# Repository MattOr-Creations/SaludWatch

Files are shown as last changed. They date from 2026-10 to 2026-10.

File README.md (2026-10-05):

# SaludWatch
The SaludWatch is a monitoring aid device to help track temperature, blood oxy and heart rate while also showing you the time. 
These functions help elderly people track their vitals and know when to take medicine without having to walk to get a device, its simple design makes it easy to understand.

I came up with the idea thanks to my grandma(As weird as it may sound). It all started with my grandma having to climb the stairs to the third floor of my three-story house because she felt dizzy, it was too much! Plus it was dangerous,
one might say "But can't you just move the monitoring aid to the first floor so she doesn't have to go all the way up?" That's an option, yes, however, my grandma likes having her items organized, moving it to the first floor would just make her forget it's there in the first place.
That's when I thought of a great invention, what if the monitoring aid was ON her at ALL times? It would probably look ugly, however if I disguise it as another device which is on you MOST of the time, like a watch, then it would be better!
And that's how SaludWatch was born, the Wi-Fi, LED and buzzer functions were added later after discovering what the ESP32-WROOM-32 has(And can do).



(Schematic of the SaludWatch)

## Now, let's get technical, how does it really work?

+ The sensors, display, buzzer, and buttons connect to an ESP32-WROOM-32 development board.
+ The board reads the sensors, draws everything on a small OLED display, and uses its built-in Wi-Fi to sync the time and send alerts.
+ A LiPo battery powers it through a TP4056 charging module with battery protection (Using the USB charger).
+ And a MT3608 step-up converter raises the battery voltage to the 5V the board needs.

```mermaid
graph TD;
    USBCharger-->TP4056;
    TP4056-->SlideSwitch;
    TP4056-->3.7VLiPobattery
    SlideSwitch-->MT3608;
    MT3608-->ESP32-WROOM-32;
    MAX30102-->|I2C|ESP32-WROOM-32;
    DS18B20-->|1-Wire|ESP32-WROOM-32;
    Buttons-->ESP32-WROOM-32;
    ESP32-WROOM-32-->|I2C|1.3inOLEDdisplay;
    ESP32-WROOM-32-->Buzzer+LED;
    ESP32-WROOM-32-->|Wi-Fi|AlertToFamily;
```

### Expected program flow
1. Boot, connect to Wi-Fi and sync to the local time zone then disconnect(Other modules are still active)
2. Time will show, the screen wakes up if any button is pressed.
3. Press the forward button to send a measurement request, wait 15-30 seconds after a "Keep still" notice, then show results on the OLED.
4. If the old person needs to take medicine soon or something is off, the buzzer will sound and the LED flash, an alert will ONLY be sent If something is off.
5. Otherwise the old person can check their vitals and then the device goes into energy-saving mode, wakes up on a button press.

## ESSENTIAL file locations

- `Hardware/` — 3D Case design and Schematic with wiring using labels
- `Hardware/Case/3DCase.f3d` — 3D Case design
- `Hardware/kicad/SaludWatch.kicad_pro` — Kicad Schematic + Wiring
- `Hardware/kicad/SaludWatch.kicad_sch` — Kicad Schematic + Wiring
- `Firmware/` — Code? Not yet, planned for the future functional prototype
- `Docs/` — Misc, non-editable files, diagrams and layout

## Layout + 3D design
The final third design of all my drawn designs, had to do a box because 3D modelling is hard ;(. (Especially considering I have never done it, I was happy once I found out I could make any weird shaped figure with the line and extrude tool!)


Board layout which I used to make the 3D Case model


Exterior view, here we can see the lid, walls and strap lugs. The lid has one hole for the OLED display and two square sized ones for the two buttons. At the strap lugs' side we can also see the slideSwitch hole and to the side another one for the DS18B20


(Only-Base view, see that hole in the distance? That's for the ESP32-WROOM32, and also opposite hole to the DS18B20 hole is for the micro-usb charger for the TP4056)


Lid+2layer view. Here we can appreciate the beautifully modelled lid, I even made a fit-able lid using the join operation with the extrude tool! And about the two layers, that coin sized hole is for the connections between all the modules. The layers aren't really attached at all, there's an space of 0.3mm from all sides with the two shelves I made[You can see them in the second pic]

## Materials list
Prices were in Peruvian soles(Since I live in Peru) so I calculated the prices using the exchange rate of Sol -> USD:
| # | Part | Qty | Unit price ($) | Total ($) | Where to buy |
|---|---|---|---|---|---|
| 1 | ESP32-WROOM-32 38-pin dev board | 1 | $11.60 | $11.60 | [Nanoparuro](https://nanoparuro.com/shop/esp32-wroom-32-c-esp-32-placa-de-desarrollo-entrada-c-38-pines-wifi-bt-1604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) |
| 2 | USB-TC 1 meter | 1 | 2.90 | 2.90 | [Nanoparuro](https://nanoparuro.com/shop/usb-tc-cable-usb-a-tipo-c-para-transferir-datos-de-1-metro-usb-tc-1610#attr=) |
| 3 | MAX30102 pulse oximeter module | 1 | 2.90 | 2.90 | [Nanoparuro](https://nanoparuro.com/shop/max30102-modulo-sensor-de-pulso-de-ritmo-cardiaco-pulsioximetro-pulsimetro-oximetro-max30102-1672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) |
| 4 | OLED 0.96in I2C display | 1 | 5.80 | 5.80 | [Nanoparuro](https://nanoparuro.com/shop/oled096-i2c-display-oled-0-96-pulgadas-i2c-oled096-i2c-1111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) |
| 5 | DS18B20 waterproof temperature probe | 1 | 2.90 | 2.90 | [Nanoparuro](https://nanoparuro.com/shop/ds18b20-cable-sensor-de-temperatura-digital-ds18b20-a-prueba-de-agua-55degc-a-125degc-304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) |
| 6 | TP4056 charger with protection | 1 | 1.42 | 1.42 | [Nanoparuro](https://nanoparuro.com/shop/tp4056-prot-tp4056-prot-cargador-con-proteccion-para-baterias-de-litio-3-7v-con-entrada-micro-usb-233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) |
| 7 | MT3608 step-up converter | 1 | 1.60 | 1.60 | [Nanoparuro](https://nanoparuro.com/shop/mt3608-mt3608-conversor-dc-dc-step-up-ajustable-2-a-24-vsal-28v-242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) |
| 8 | Slide switch KBB-20 | 1 | 0.35 | 0.35 | [Nanoparuro](https://nanoparuro.com/shop/kbb-20-switch-deslizable-2-posiciones-kbb-20-132?search=KBB-2&order=name+asc#attr=) |
| 9 | 3.7V 1000 mAh LiPo battery | 1 | 4.35 | 4.35 | [Nanoparuro](https://nanoparuro.com/shop/bateria-de-3-7v-litio-366?search=Bateria&order=name+asc#attr=550) |
| 10 | D830B Multimeter | 1 | 5.79 | 5.79 | [Nanoparuro](https://nanoparuro.com/shop/dt-830d-multimetro-digital-con-puntas-de-prueba-d830b-203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) |
| | **Total** | | | **$39.61** | **about $39.61** |

## Limitations
Some parts such as the ESP32 board, the battery, the step up, and DS18B20 are very large and are only meant to prove the functionality of the prototype, they will change in a later version(They are also the only ones I found available near my hometown). I might also have mentioned that a blood pressure module would be added, but since they are VERY expensive(40$) and exceed the budget, those will be totally optional.

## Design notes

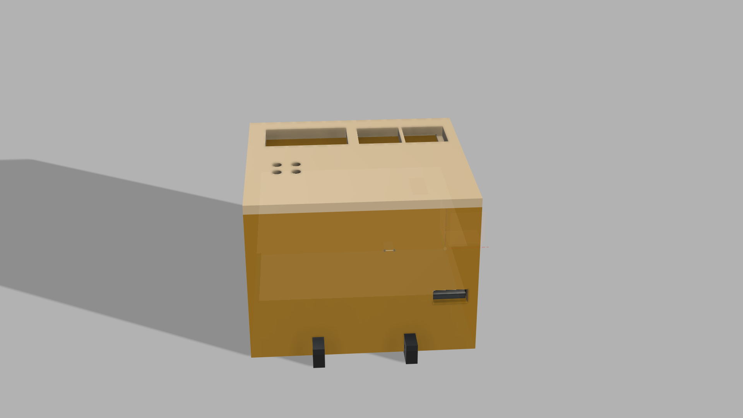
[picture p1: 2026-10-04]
Docs/SaludWatch3D.png

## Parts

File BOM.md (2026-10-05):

# SaludWatch — bill of materials

<!-- Generated by Half Life from project cmuovdwnd01sl01s1f6d9b2td. Edits here are overwritten on the next sync. -->
<!-- Generated: 2026-10-05T01:47:07.764Z -->

> [!NOTE]
> This parts list is mirrored from [Half Life](https://halflife.hackclub.com). Editing it here will not change the platform's copy, and the next sync overwrites this file.

| Week | Tier | Parts funding |
| --- | --- | --- |
| Warm-up | Tier 2 | $65.00 |

| Part | What it's for | Qty | Unit | Total | Vendor |
| --- | --- | --- | --- | --- | --- |
| [OLED 0.96inch 12c display](https://nanoparuro.com/shop/oled096-i2c-display-oled-0-96-pulgadas-i2c-oled096-i2c-1111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) | Display | 1 | $5.80 | $5.80 | [Nanoparuro](https://nanoparuro.com/shop/oled096-i2c-display-oled-0-96-pulgadas-i2c-oled096-i2c-1111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) |
| [TP4056 charger with protection](https://nanoparuro.com/shop/tp4056-prot-tp4056-prot-cargador-con-proteccion-para-baterias-de-litio-3-7v-con-entrada-micro-usb-233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) | Charging the battery | 1 | $1.42 | $1.42 | [Nanoparuro](https://nanoparuro.com/shop/tp4056-prot-tp4056-prot-cargador-con-proteccion-para-baterias-de-litio-3-7v-con-entrada-micro-usb-233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) |
| [3.7V 1000 mAh LiPo battery](https://nanoparuro.com/shop/bateria-de-3-7v-litio-366?search=Bateria&order=name+asc#attr=550) | Power | 1 | $4.35 | $4.35 | [Nanoparuro](https://nanoparuro.com/shop/bateria-de-3-7v-litio-366?search=Bateria&order=name+asc#attr=550) |
| [MAX30102  pulse oximeter module](https://nanoparuro.com/shop/max30102-modulo-sensor-de-pulso-de-ritmo-cardiaco-pulsioximetro-pulsimetro-oximetro-max30102-1672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) | Heart rate sensor | 1 | $2.90 | $2.90 | [Nanoparuro](https://nanoparuro.com/shop/max30102-modulo-sensor-de-pulso-de-ritmo-cardiaco-pulsioximetro-pulsimetro-oximetro-max30102-1672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) |
| [DS18B20 waterproof probe](https://nanoparuro.com/shop/ds18b20-cable-sensor-de-temperatura-digital-ds18b20-a-prueba-de-agua-55degc-a-125degc-304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) | Temperature sensor | 1 | $2.90 | $2.90 | [Nanoparuro](https://nanoparuro.com/shop/ds18b20-cable-sensor-de-temperatura-digital-ds18b20-a-prueba-de-agua-55degc-a-125degc-304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) |
| [KBB-20](https://nanoparuro.com/shop/kbb-20-switch-deslizable-2-posiciones-kbb-20-132?search=KBB-2&order=name+asc#attr=) | Power Switch | 1 | $0.35 | $0.35 | [Nanoparuro](https://nanoparuro.com/shop/kbb-20-switch-deslizable-2-posiciones-kbb-20-132?search=KBB-2&order=name+asc#attr=) |
| [ESP32-WROOM-32](https://nanoparuro.com/shop/esp32-wroom-32-c-esp-32-placa-de-desarrollo-entrada-c-38-pines-wifi-bt-1604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) | Wi-Fi and the main loop | 1 | $11.60 | $11.60 | [Nanoparuro](https://nanoparuro.com/shop/esp32-wroom-32-c-esp-32-placa-de-desarrollo-entrada-c-38-pines-wifi-bt-1604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) |
| [D830B Multimeter](https://nanoparuro.com/shop/dt-830d-multimetro-digital-con-puntas-de-prueba-d830b-203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) | To calibrate MT3608 | 1 | $5.79 | $5.79 | [Nanoparuro](https://nanoparuro.com/shop/dt-830d-multimetro-digital-con-puntas-de-prueba-d830b-203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) |
| [MT3608 step up](https://nanoparuro.com/shop/mt3608-mt3608-conversor-dc-dc-step-up-ajustable-2-a-24-vsal-28v-242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) | Power adapter | 1 | $1.60 | $1.60 | [Nanoparuro](https://nanoparuro.com/shop/mt3608-mt3608-conversor-dc-dc-step-up-ajustable-2-a-24-vsal-28v-242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) |
| [USB-TC 1 meter](https://nanoparuro.com/shop/usb-tc-cable-usb-a-tipo-c-para-transferir-datos-de-1-metro-usb-tc-1610#attr=) | Charging purposes | 1 | $2.90 | $2.90 | [Nanoparuro](https://nanoparuro.com/shop/usb-tc-cable-usb-a-tipo-c-para-transferir-datos-de-1-metro-usb-tc-1610#attr=) |
| **Parts subtotal** | — | — | — | **$39.61** | — |
| **Tax & shipping** | — | — | — | **$0.00** | — |
| **Total** | — | — | — | **$39.61** | — |

$25.39 left of the tier's funding.

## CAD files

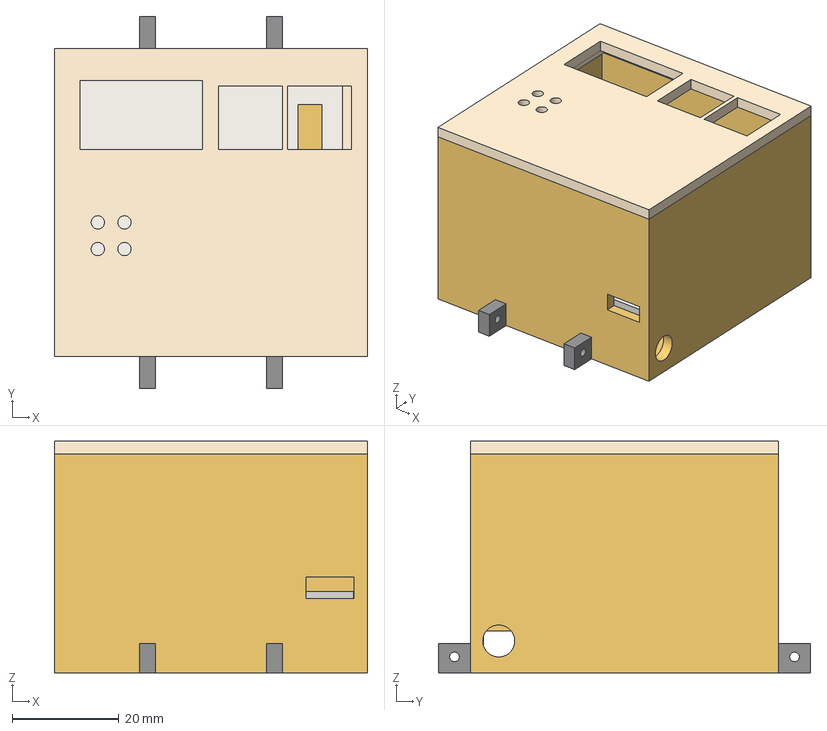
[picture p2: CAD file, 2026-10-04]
Hardware/Case/3DCase.step
58.8 x 69.8 x 43.5 mm

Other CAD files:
Hardware/Case/3DCase.f3d
Hardware/Case/3DCase.stl

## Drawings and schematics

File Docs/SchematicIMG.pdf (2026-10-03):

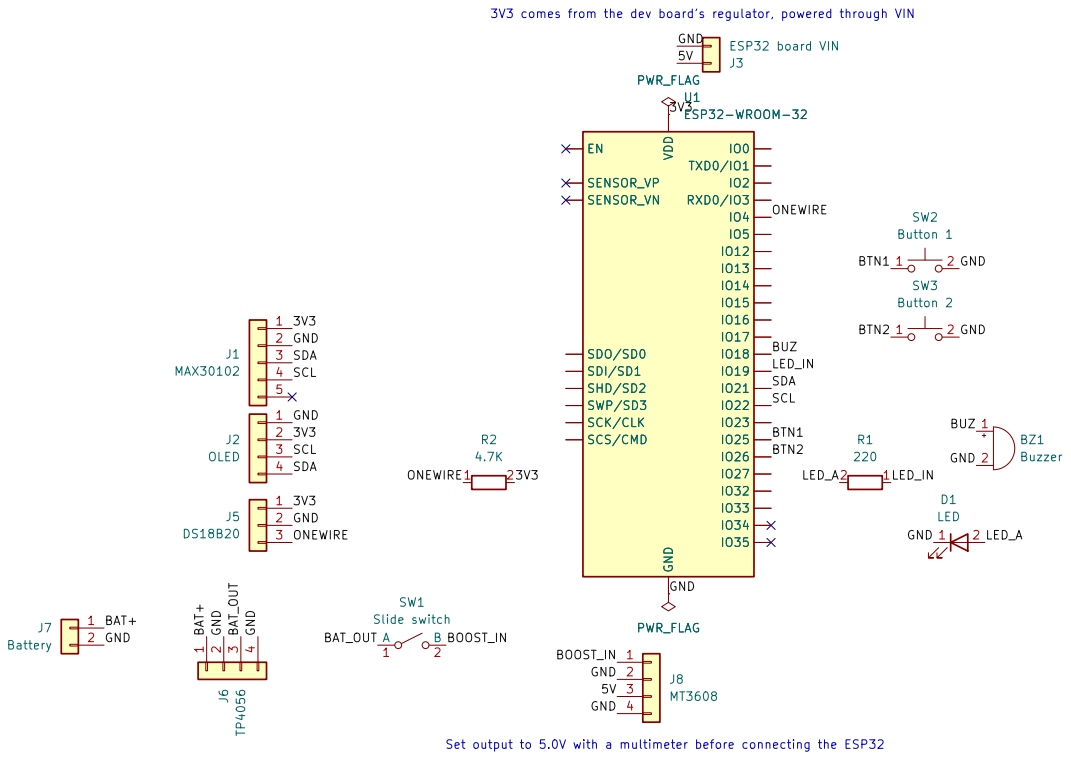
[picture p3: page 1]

3V3 comes from the dev board's regulator, powered through VIN
ESP32-WROOM-32
IO21 RXD0/IO3

Size: A4 | Rev:
KiCad E.D.A. 10.0.6 | Id: 1/1

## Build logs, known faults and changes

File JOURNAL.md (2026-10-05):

# SaludWatch — devlog

<!-- Generated by Half Life from project cmuovdwnd01sl01s1f6d9b2td. Edits here are overwritten on the next sync. -->
<!-- Generated: 2026-10-05T01:25:07.580Z -->

> [!NOTE]
> This devlog is mirrored from [Half Life](https://halflife.hackclub.com). Editing it here will not change the platform's copy, and the next sync overwrites this file.

> A wristwatch for elder people that also measures heart rate, blood oxygen and skin temperature with sensors connected to a ESP32-WROOM-32 38-pin dev board. It uses the board's built-in Wi-Fi for the time syncronization and to send alerts to nearby familiars If any value is not adequate. Since it's built for elder people it will have large buttons and just a few functions that are easy to comprehend. Useful If you have familiars that want to check their vitals at any moment of the day while also getting to know when they should take their medicine.

| Week | Tier | Hours logged | Entries |
| --- | --- | --- | --- |
| Warm-up | Tier 2 | 19h | 3 |

## Contents

1. [2026-10-02 — SaludWatch &lt;09/30/26 - 10/02/26&gt; | Researched design, parts and functions!](#2026-10-02-saludwatch-lt093026---100226gt-researched-design-)
2. [2026-10-03 — SaludWatch - 10/03/26 - Finally figured out the final parts and made a schematic using KiCad!](#2026-10-03-saludwatch---100326---finally-figured-out-the-fin)
3. [2026-10-04 — SaludWatch - 10/04/26 - FINALLY!! 3D Design DONE, Diagrams ReDONE, Repository Done!](#2026-10-04-saludwatch---100426---finally-3d-design-done-diag)

## Design

### 2026-10-02 — SaludWatch &lt;09/30/26 - 10/02/26&gt; | Researched design, parts and functions!

**7h**

SaludWatch <09/30/26 - 10/02/26> | Researched design, parts and functions!

(September 30)

Looked up what I could need to create the SaludWatch, it turns out I need the microcontroller ESP32-C3 with built-in Wi-Fi for the project, aw man I  had a really nice Arduino Uno R3, I guess you could say it's time to go... Wireless.


Additionally, I decided to do a quick sketch of how the SaludWatch could look:
WhatsApp Image 2026-10-01 at 11.39.08 PM
(Not sure of the specific parts yet, will look into it!)

(October 1)

Finally looked into the specific parts and had to discard a few parts like the TMP117 and MAX30205 to replace them with available ones in peruvian electronics shops like the DS18B20 for temperature and the MAX30102 for the heart rate:

(The battery size shouldn't affect the invention's success, hopefully)

Also, since I had to choose a smaller version of the ESP32-C3 I decided to include a TP4056 charger module with battery protection to prevent over-discharging the battery


(October 2)
WhatsApp Image 2026-10-02 at 9.57.48 PM
Found out my previously bought Arduino Learning Kit had a few parts necessary for the project(Buzzer, cables, resistances, LEDs).

Had to learn to use Mermaid javascript tool for diagramming and charting. Made 3 commits to SaludWatch repository, added block diagram.

Also decided to learn more about KiCad. This'll help get a more polished design.

### 2026-10-03 — SaludWatch - 10/03/26 - Finally figured out the final parts and made a schematic using KiCad!

**6h**

SaludWatch - 10/03/26 - Finally figured out the final parts and made a schematic using KiCad!

(October 3)


After a few hours I finally managed to get the final list for the project! Replaced the ESP32-C3 Super Mini for a ESP32-WROOM-32, and had to add the small boost converter MT3608 for the microcontroller to work with the 3.7V battery.

Also included a Multimeter to calibrate the volts of the MT3608 and for safety reasons.

Worked on the KiCad schematic, took me a really good time to comprehend what symbols to add but I managed it! Also, pointed out the wiring with labels since standard wires take too much space. Faced some problems with the pin names and reference names covering too much, though I managed to find the option to hide them after some exploring. Also improved the organization in my repository added the schematic, going to update README.md soon, weekends are such great days to work on this project :)

(Found a symbol fo my exact ESP32 model, nice!)

(Still quite new to managing repositories, I'm improving!)

(Updated Block diagram)
WhatsApp Image 2026-10-03 at 10.06.55 PM
Did a better sketch of how my invention could look, still not final though, noticed I have to include a CAD 3D design of my invention and found out about Fusion, tried it for a bit but couldn't get too far, I'm going to look more into it.

### 2026-10-04 — SaludWatch - 10/04/26 - FINALLY!! 3D Design DONE, Diagrams ReDONE, Repository Done!

**6h**

SaludWatch - 10/04/26 - FINALLY!! 3D Design DONE, Diagrams ReDONE, Repository Done!

 (October 4)

Made a layout for the SaludWatch, this is an improved version of my previous 2 sketches, It's the prototype version, which is a better arrangement of the pieces inside a case. Though, since it's the prototype version, it still does have some limitations. I added the layout and a Improved version of the block diagram, it's colored now!




Last time I was checking out Fusion 360 for 3D modelling, and guess what?


I made the 3D design wohoo!!!! (Yeah yeah a box, that's what it looks like, it would have had a better shape but I was in a rush. Those are not all the complements though, I'll show you the layers)







Here's the features in a list since writing beneath each pic would just take too long:

1.Here's the shelf plates, they are removable and are supported by the internal ledges in the base, each plate have a coin-shaped slot so wires can pass between the decks

2.Here's the base part of the case, it has port openings for the TP4056 micro-USB charger, ESP32 USB-C, a slot for the slide switch lever and a hole for the DS18B20 cable. If you've noticed, at the sides there's two lug straps, those are for the watch straps, part of the design! You can also see both internal ledges in this picture.

3.And finally the grand... Lid! I'm really proud of it, not just for the cutouts for the OLED, buttons and buzzers, but for it's ability to actually fit in the base! The ring under it does the magic.

[Repository Done!!!!!!]



So so many commits, I've added the materials and price list to the README.md since it was required(Vendors too), added limitations, 3D design, layout and replaced my 1st sketch of the SaludWatch with the schematic. Also added important file locations for easier repository exploration.

I'm really looking forward to building this project!

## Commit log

2026-10-04 Added SaludWatch 3D design
    [3D Case.f3d, SaludWatch.step, SaludWatch.stl]
2026-10-04 Rename 3D Case.f3d to 3DCase.f3d
    [3DCase.f3d]
